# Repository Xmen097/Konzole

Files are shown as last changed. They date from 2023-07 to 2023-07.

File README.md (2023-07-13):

# Konzole
Herní konzole s Atmega328 vytvořená v rámci kroužku v DDM Praha 6.

##### Hardware
- TFT display 320x240
- Custom joystick
- 8 tlačítek
- IR vysílač a přijímač
- Otočný potenciometr
- Nabíjecí li-ion baterie s nabíjecím obvodem na micro USB

##### Software
Implementovány byly hry:
 Pong, Tetris, Snake (credits: Vojtěch Černý), pacman, Space shooter

##### Obrázky
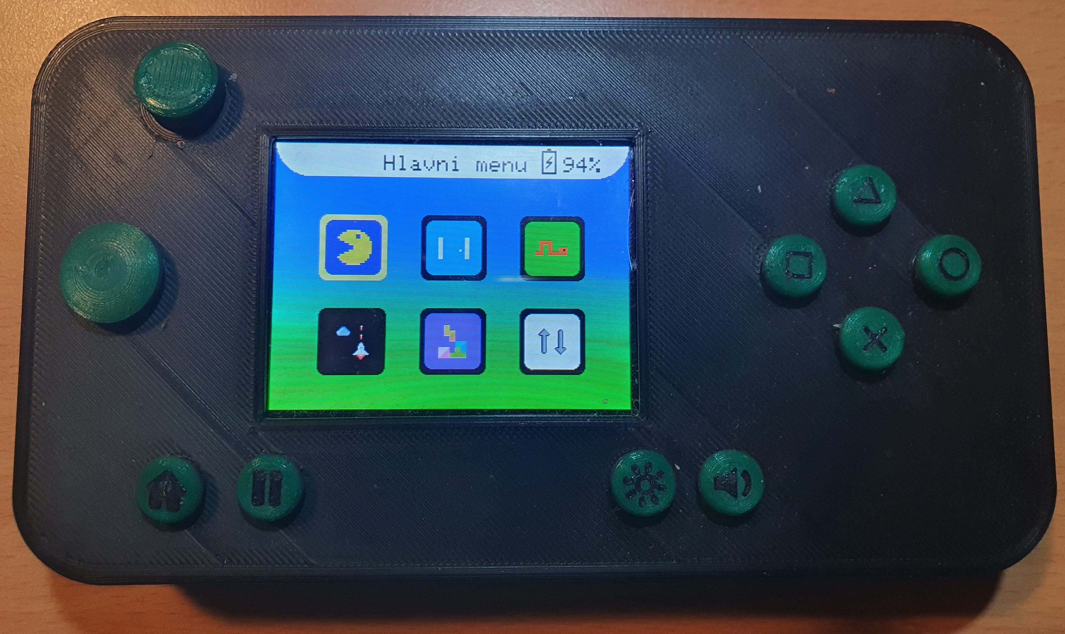
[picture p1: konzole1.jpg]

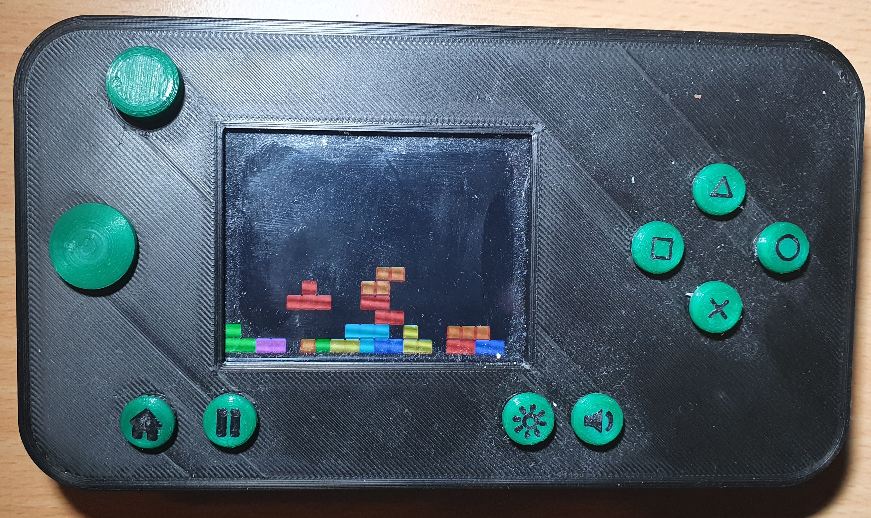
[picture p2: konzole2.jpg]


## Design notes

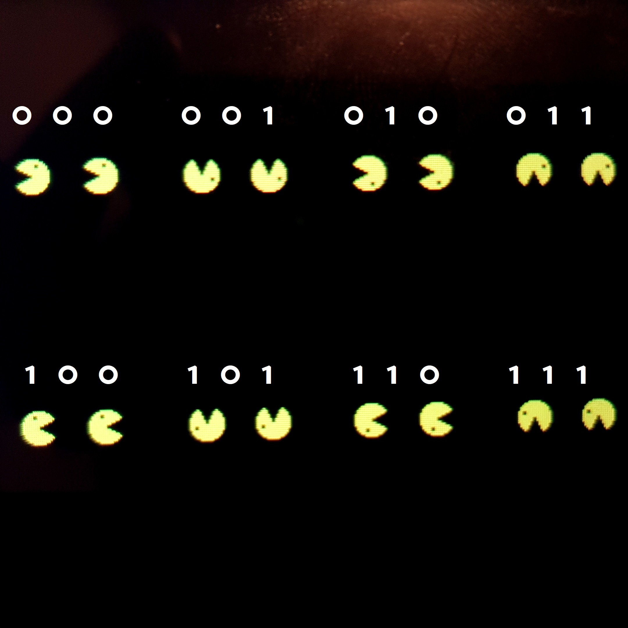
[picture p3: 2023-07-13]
konzole_smery.jpg

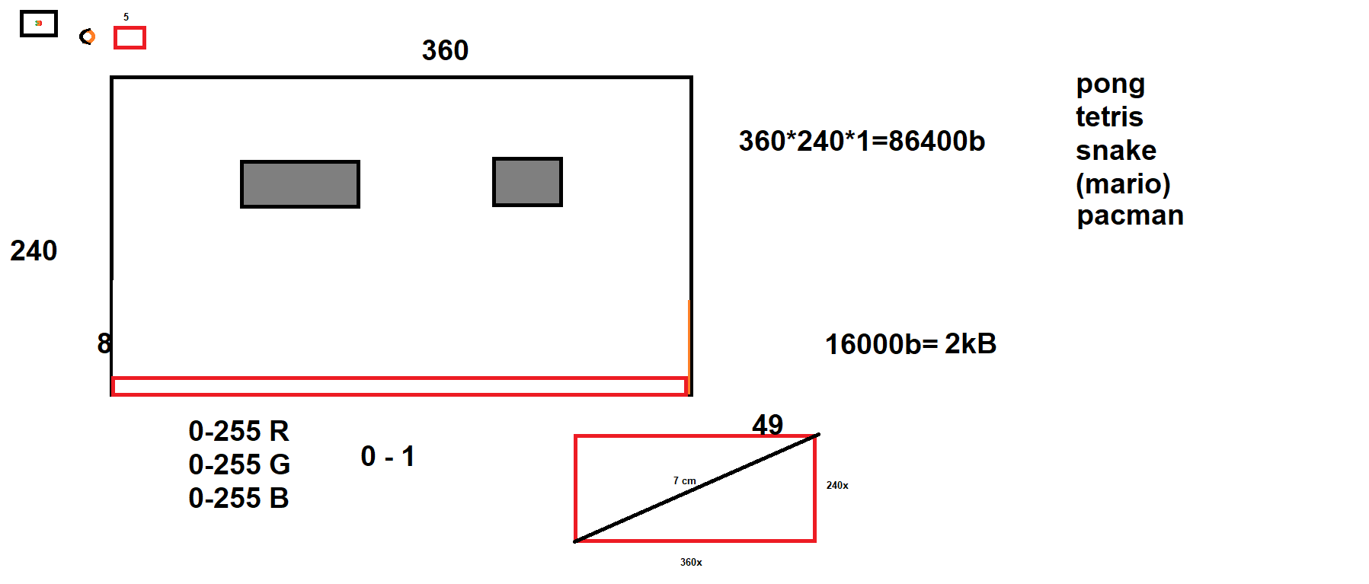
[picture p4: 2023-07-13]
konzole.png

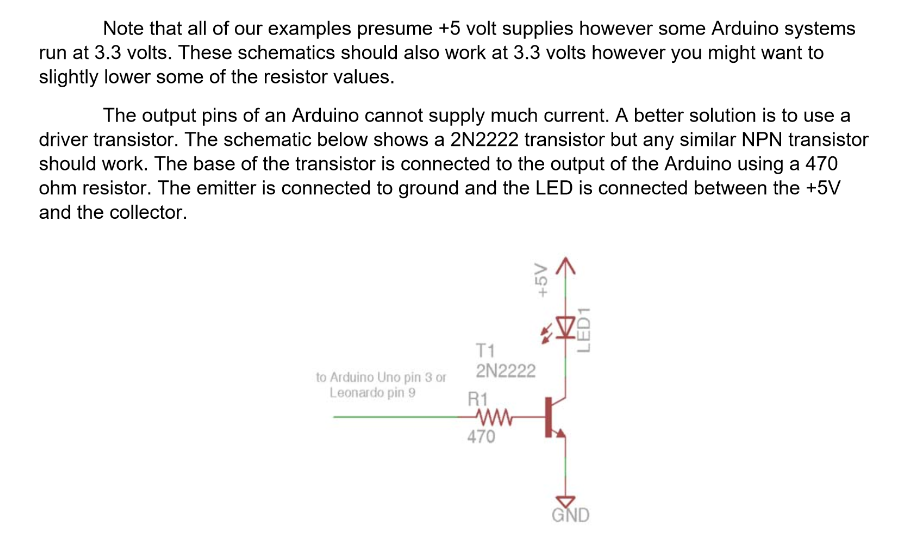
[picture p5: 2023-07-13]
IR drive circuit.png

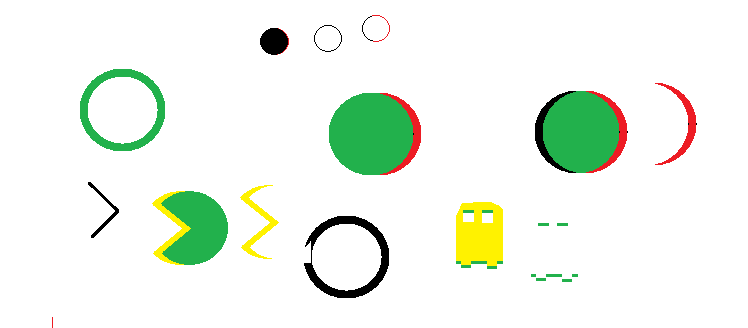
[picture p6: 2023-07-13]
rendering.png

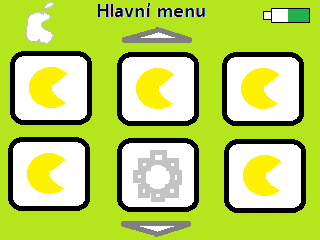
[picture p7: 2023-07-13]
hlavni menu.png

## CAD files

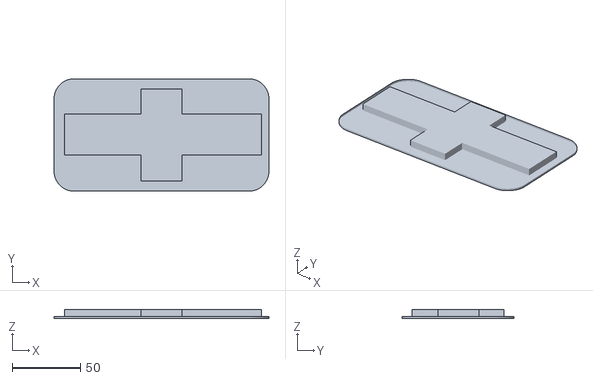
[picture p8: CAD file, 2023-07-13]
export/zada.stl
157.0 x 82.0 x 6.50

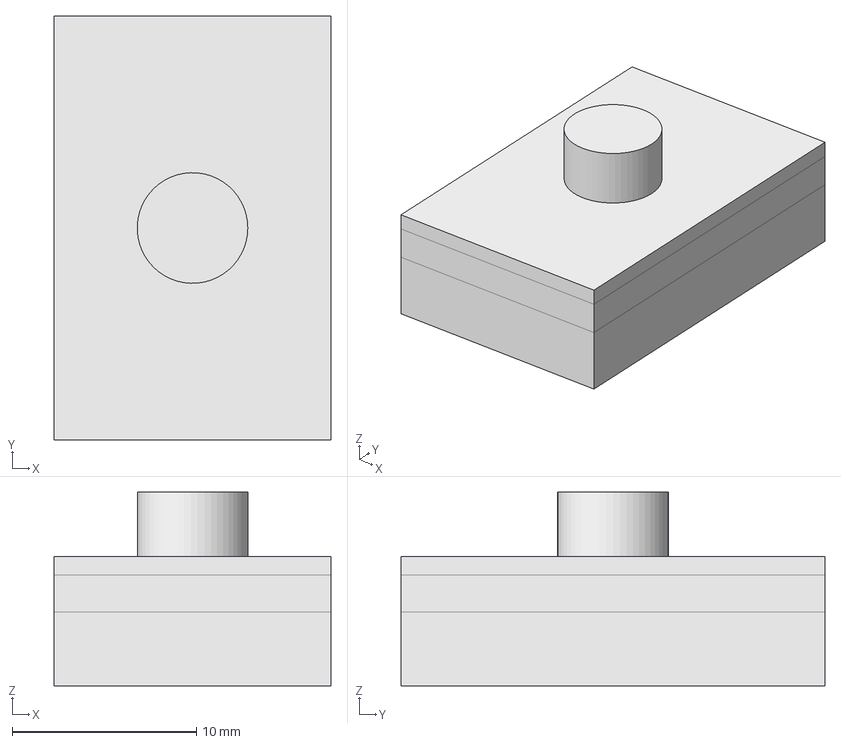
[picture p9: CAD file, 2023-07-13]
Konzole - modely/Joystick.FCStd
15.0 x 23.0 x 10.5 mm

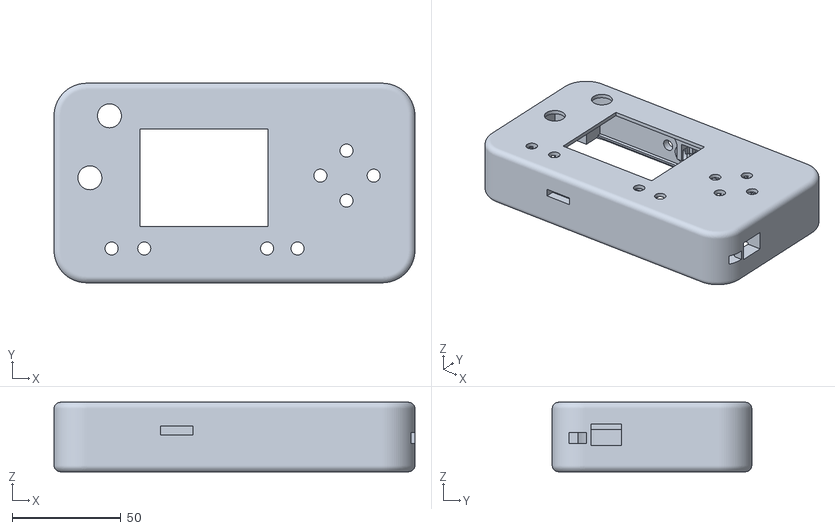
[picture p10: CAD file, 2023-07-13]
export/krabicka.stl
166.0 x 91.8 x 32.0

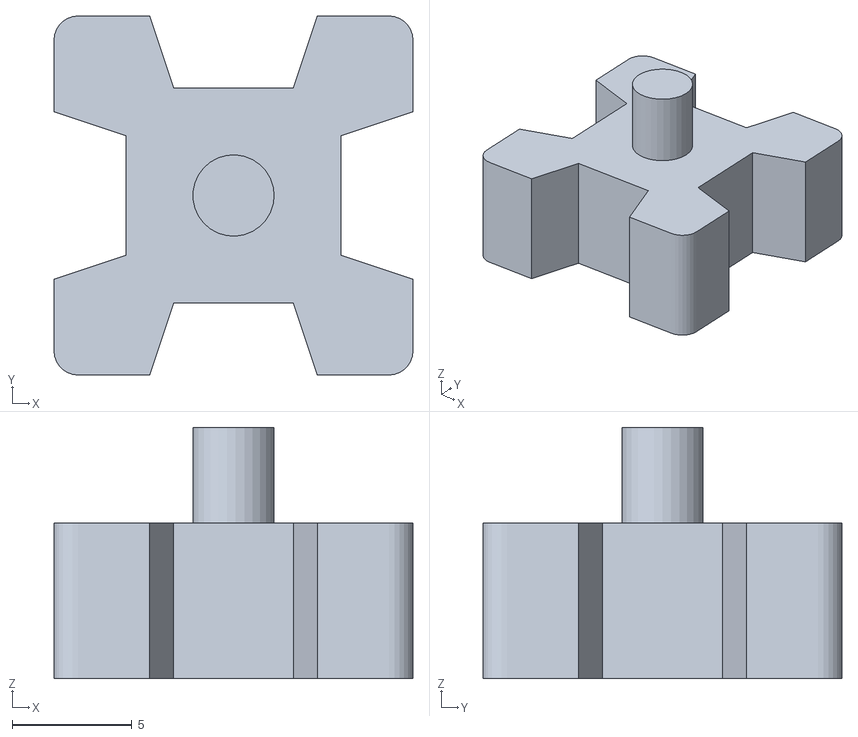
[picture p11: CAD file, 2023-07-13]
Konzole - modely/joystick_middle.stl
15.0 x 15.0 x 10.5

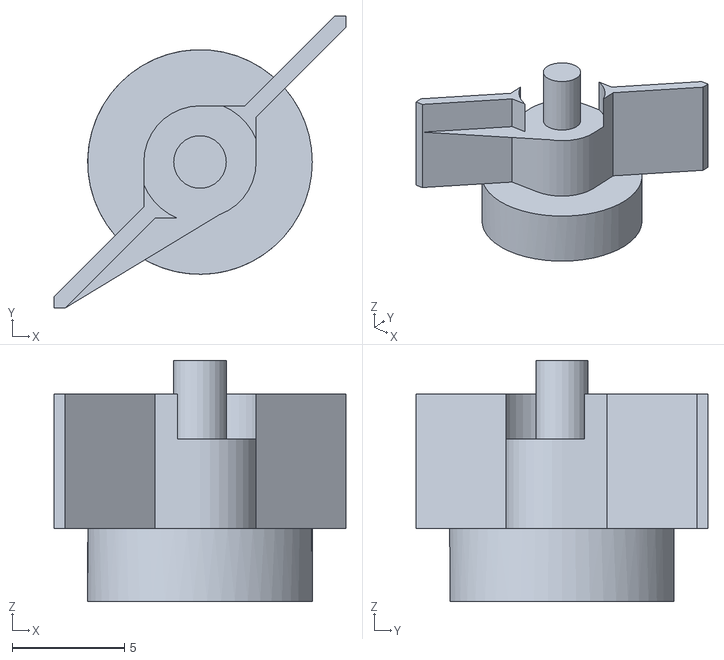
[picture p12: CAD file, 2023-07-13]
export/tlacitko_spodek.stl
13.0 x 13.0 x 10.8

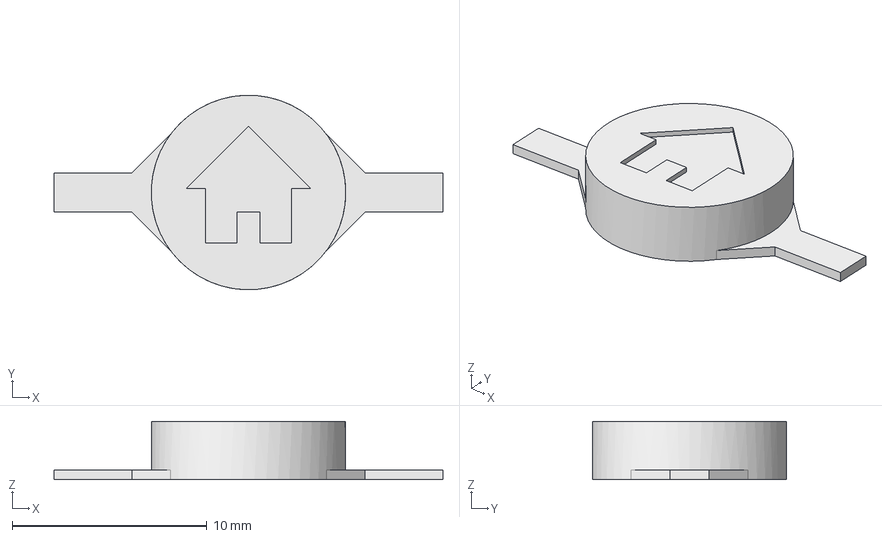
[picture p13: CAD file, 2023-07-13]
Konzole - modely/Test_tlacitek.FCStd
20.0 x 10.00 x 3.00 mm

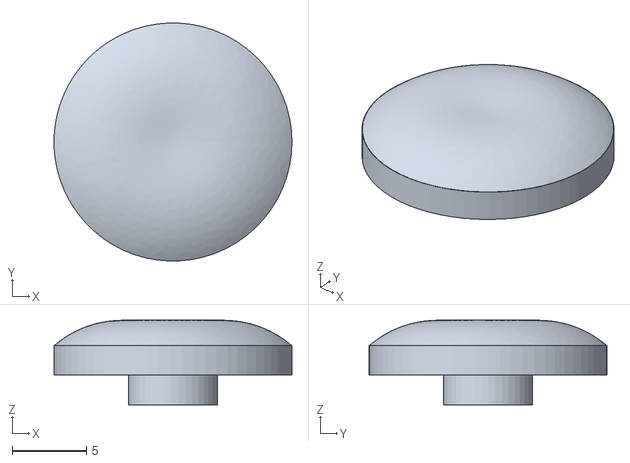
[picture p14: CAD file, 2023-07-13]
export/joystick_hmatnik.stl
16.0 x 16.0 x 5.69

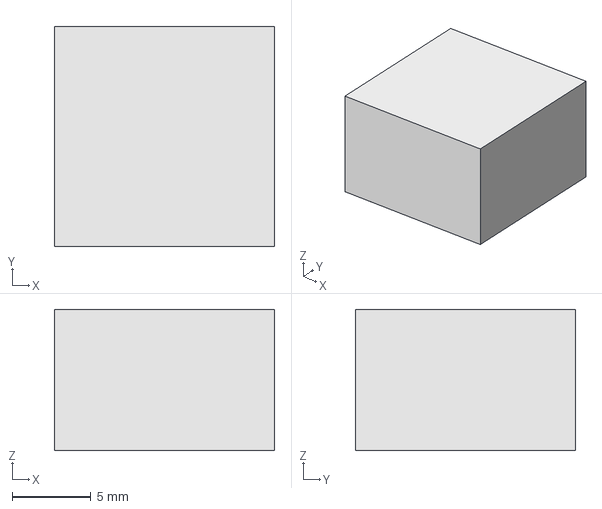
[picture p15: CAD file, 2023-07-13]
Konzole - modely/Master.FCStd
14.0 x 14.0 x 9.00 mm

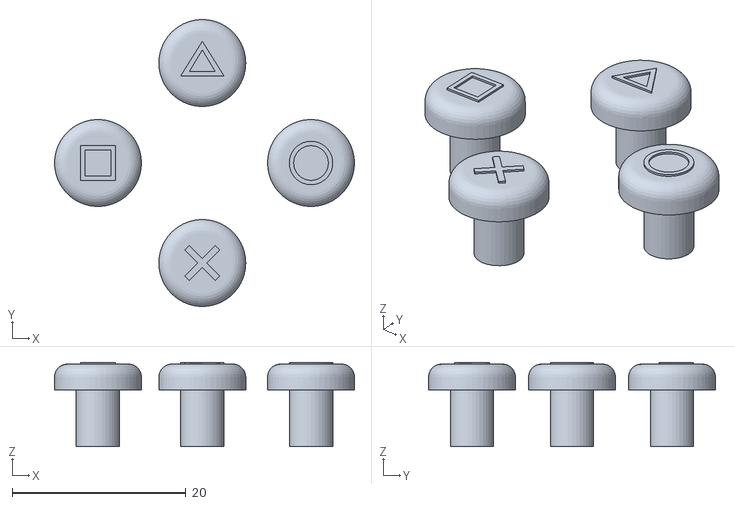
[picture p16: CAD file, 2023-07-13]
export/tlacitka_napravo.stl
34.5 x 33.0 x 9.70

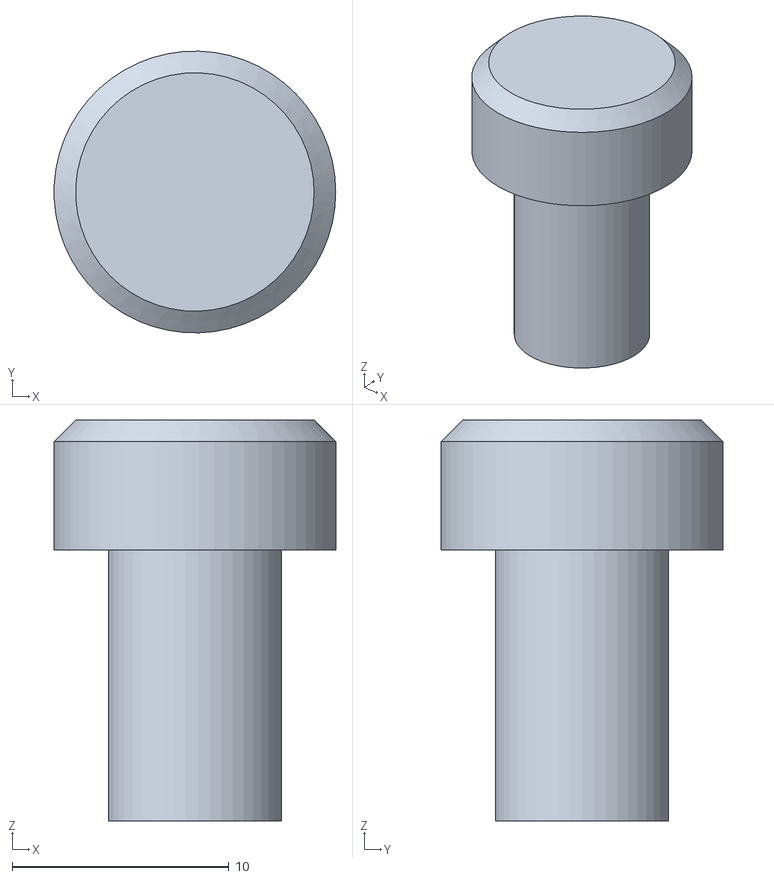
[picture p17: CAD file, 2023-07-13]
export/hlasitost.stl
13.0 x 13.0 x 18.5

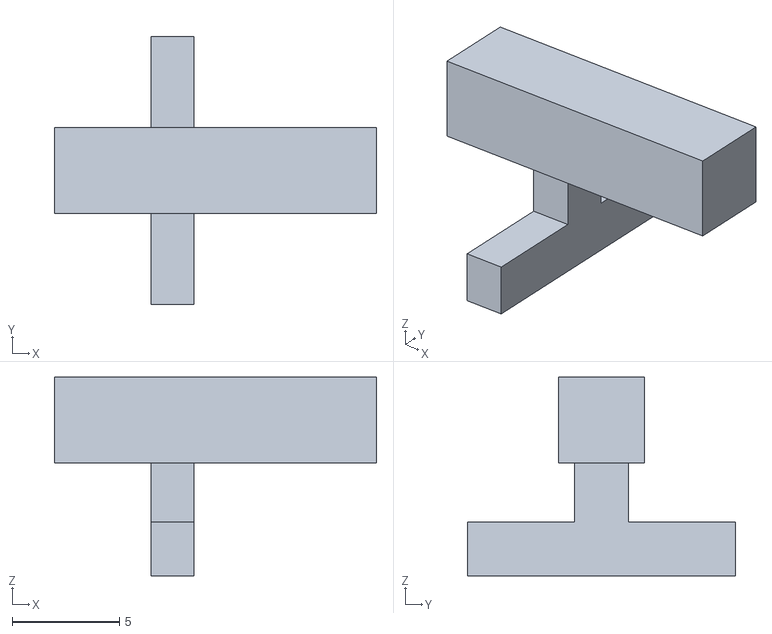
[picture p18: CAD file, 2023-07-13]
export/prepinac.stl
15.0 x 12.5 x 9.25

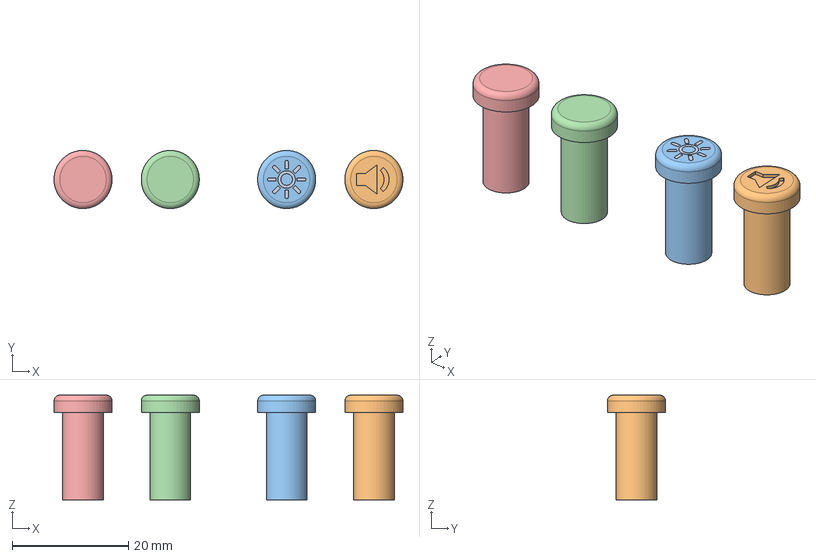
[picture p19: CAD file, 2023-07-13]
Konzole - modely/Button.FCStd
60.0 x 10.00 x 18.0 mm
ZákladTlačítka
TlacitkoMute
TlacitkoJas
TlacitkoPause
TlacitkoHome

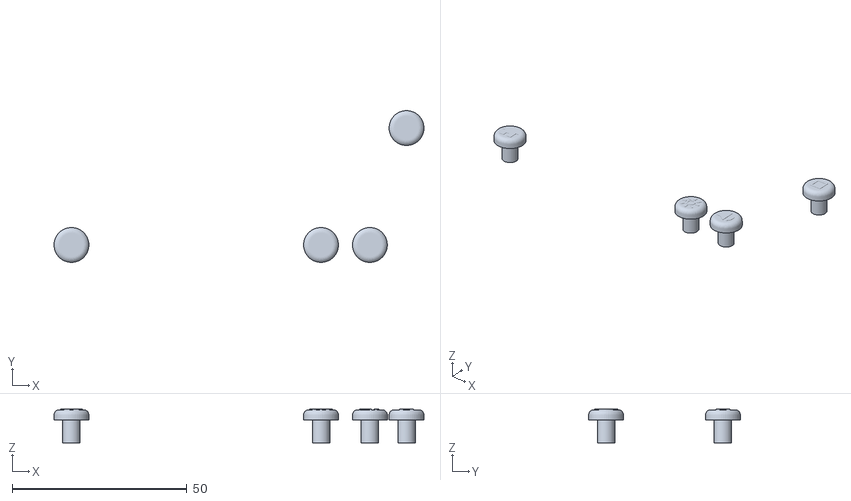
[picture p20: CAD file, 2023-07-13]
export/tlacitka_repair.stl
106.0 x 43.5 x 9.70

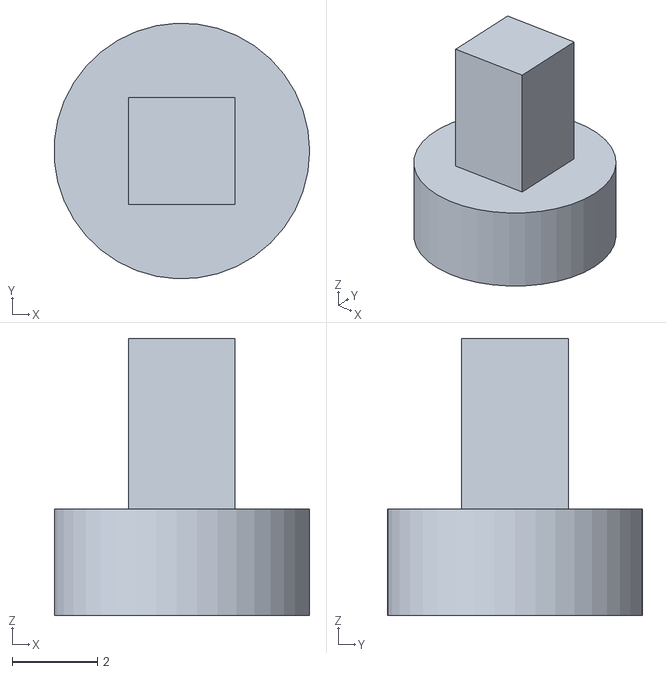
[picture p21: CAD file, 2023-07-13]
export/joystick_spodek.stl
5.99 x 6.00 x 6.50

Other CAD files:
Konzole - modely/test.stl
Konzole - modely/joystick_under.stl
Konzole - modely/joystick_top.stl
Konzole - modely/joystick_bottom.stl
export/joystick_prostredek.stl
export/tlacitka_akcni.stl

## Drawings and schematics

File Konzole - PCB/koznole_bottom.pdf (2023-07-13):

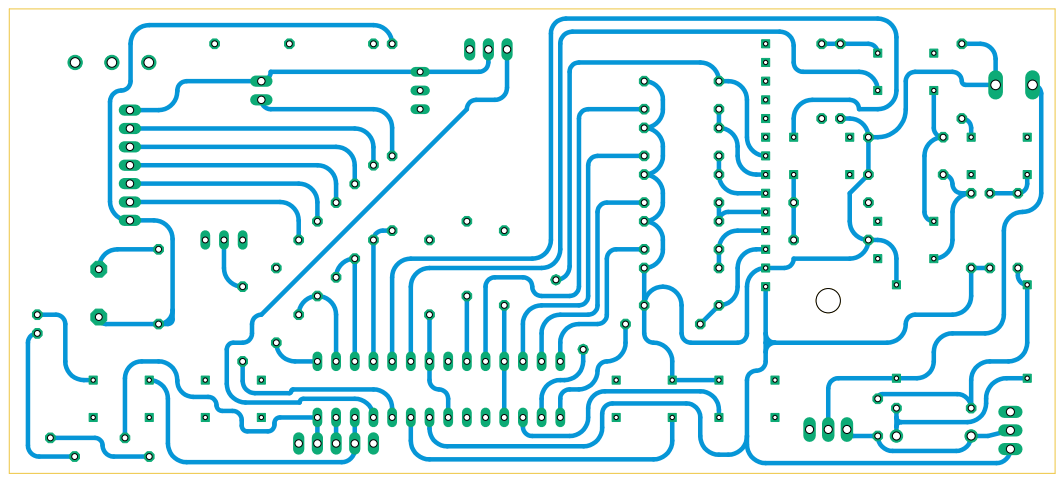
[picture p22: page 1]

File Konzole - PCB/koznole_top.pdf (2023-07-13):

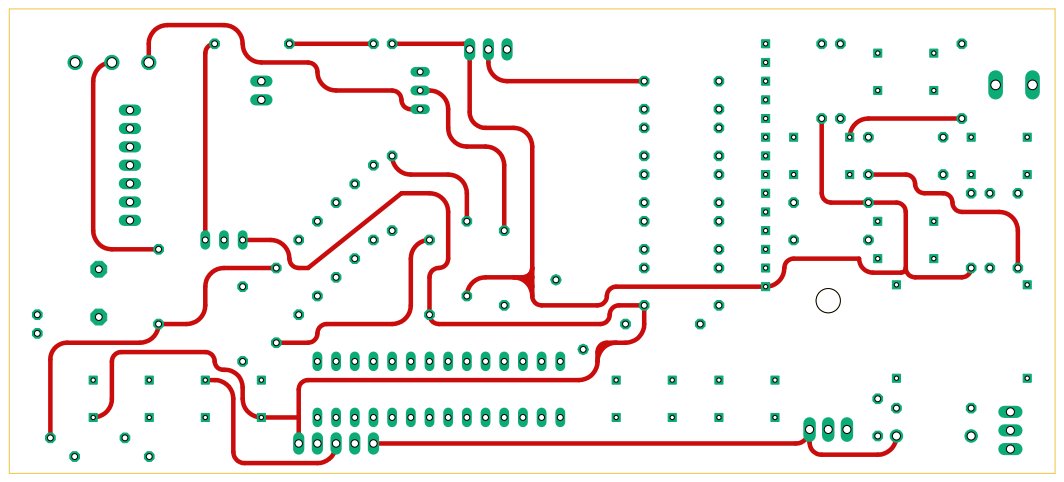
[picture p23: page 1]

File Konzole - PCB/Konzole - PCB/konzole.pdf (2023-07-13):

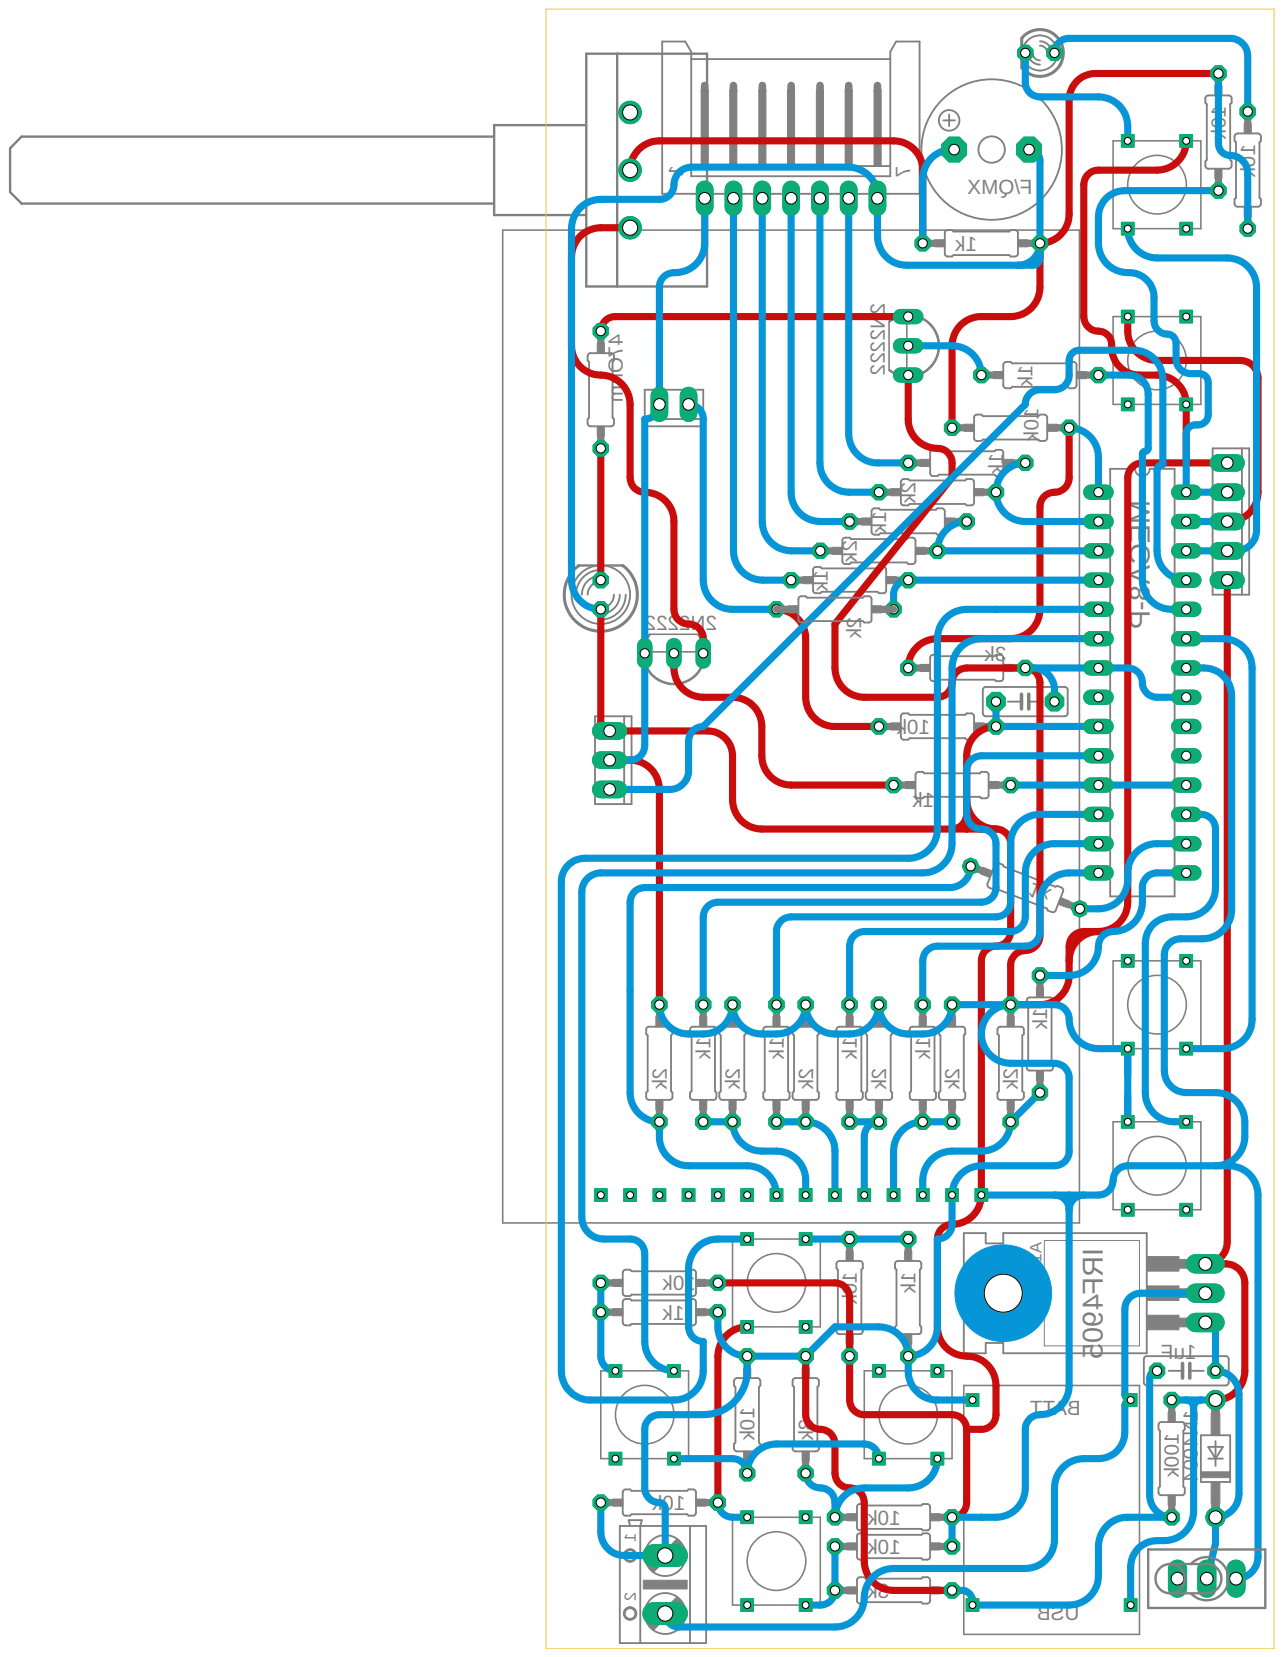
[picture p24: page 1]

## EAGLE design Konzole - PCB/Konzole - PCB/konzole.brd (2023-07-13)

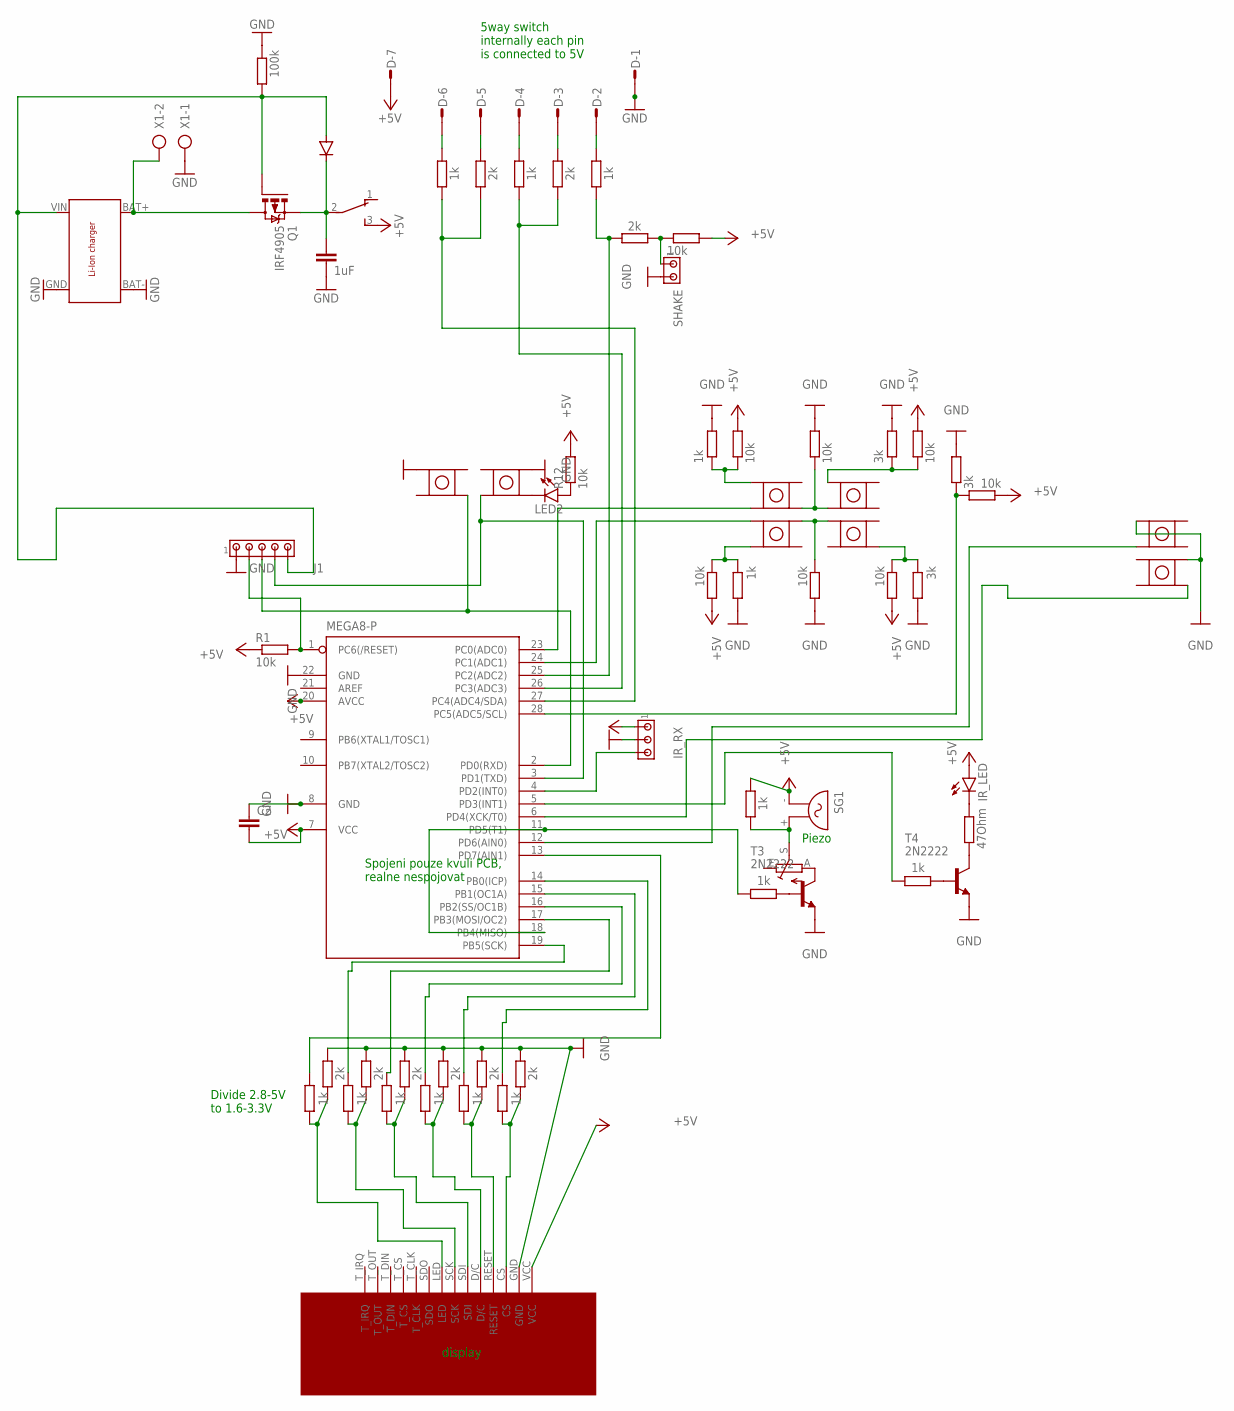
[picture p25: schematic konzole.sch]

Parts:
C1: 1uF; C050-025X075
C2: C5/2.5; C5B2.5
D: L07P
D1: 1N4004; DO41-10
IC1: MEGA8-P; DIL28-3
IR_LED: LED5MM
IR_RX: MTA03-100; 10X03MTA
J1: MTA05-100; 10X05MTA
LED2: LED3MM
Q1: IRF4905; TO220BH
R1, R12, R14, R16, R18, R20, R22, R23, R29, R49: 10k; 0207/10
R2, R4, R6, R8, R10, R15, R19, R24, R26, R27, R33, R35, R38, R40: 1k; 0207/10
R3, R5, R7, R9, R11, R25, R36, R39, R41: 2k; 0207/10
R13, R17, R21: 3k; 0207/10
R28: TRIM_EU-CIP20C-6MM; CIP20C-6MM
R34: 47Ohm; 0207/10
R42: 100k; 0207/10
S1: TL36PO; TL3XPO
SG1: F/QMX
SHAKE: MTA02-100; 10X02MTA
T3, T4: 2N2222; TO92-EBC-OVAL
U$1, U$3, U$4, U$5, U$6, U$7, U$8, U$9: TACT
U$2: DISPLAY
U$10: LI_ION_CHARGER
X1: AK500/2

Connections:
+5V: C2.2, D.7, IC1.7 (VCC), IC1.20 (AVCC), IR_LED.A, IR_RX.1, R1.1, R12.2, R14.2, R16.2, R18.2, R20.2, R27.2, R29.1, R49.2, S1.3 (S), SG1.- (1), U$2.VCC
GND: C1.2, C2.1, D.1, IC1.8 (GND), IC1.22 (GND), IR_RX.2, J1.1, R3.2, R5.2, R7.2, R9.2, R11.2, R13.2, R15.2, R17.2, R19.2, R21.2, R22.2, R23.2, R25.2, R42.2, SHAKE.2, T3.E, T4.E, U$2.GND, U$6.P$4 (4), U$7.P$1 (1), U$8.P$1 (1), U$9.P$4 (4), U$10.BAT-, U$10.GND, X1.1
unnamed: IC1.1 (PC6(/RESET)), J1.2, R1.2
unnamed: R2.2, R3.1, U$2.CS
unnamed: R4.2, R5.1, U$2.RESET
unnamed: R6.2, R7.1, U$2.D/C
unnamed: R8.2, R9.1, U$2.SDI
unnamed: R10.2, R11.1, U$2.SCK
unnamed: IC1.17 (PB3(MOSI/OC2)), R8.1
unnamed: IC1.13 (PD7(AIN1)), R24.1
unnamed: IC1.16 (PB2(SS/OC1B)), R6.1
unnamed: IC1.15 (PB1(OC1A)), R4.1
unnamed: R14.1, R15.1, U$1.P$1 (1)
unnamed: R27.1, R28.S, SG1.+ (2)
unnamed: IC1.19 (PB5(SCK)), R10.1
unnamed: R16.1, R17.1, U$5.P$1 (1)
unnamed: R18.1, R19.1, U$3.P$2 (2)
unnamed: R20.1, R21.1, U$4.P$3 (3)
unnamed: R33.2, T4.B
unnamed: LED2.K (C), U$9.P$3 (3)
unnamed: IC1.2 (PD0(RXD)), J1.3, U$8.P$3 (3)
unnamed: IC1.3 (PD1(TXD)), J1.4, U$9.P$2 (2)
unnamed: R23.1, U$3.P$4 (4), U$4.P$1 (1)
unnamed: R22.1, U$1.P$3 (3), U$5.P$2 (2)
unnamed: IC1.23 (PC0(ADC0)), U$1.P$2 (2)
unnamed: R24.2, R25.1, U$2.LED
unnamed: IC1.24 (PC1(ADC1)), U$3.P$1 (1)
unnamed: R34.1, T4.C
unnamed: IC1.11 (PD5(T1)), IC1.18 (PB4(MISO)), R26.1
unnamed: R26.2, T3.B
unnamed: R28.A, T3.C
unnamed: IC1.14 (PB0(ICP)), R2.1
unnamed: IC1.12 (PD6(AIN0)), U$7.P$2 (2)
unnamed: IC1.28 (PC5(ADC5/SCL)), R13.1, R29.2
unnamed: IC1.6 (PD4(XCK/T0)), U$6.P$3 (3)
unnamed: LED2.A, R12.1
unnamed: IC1.4 (PD2(INT0)), IR_RX.3
unnamed: IR_LED.K (C), R34.2
unnamed: IC1.5 (PD3(INT1)), R33.1
unnamed: D.6, R38.2
unnamed: D.5, R36.2
unnamed: D.4, R35.2
unnamed: Q1.D, U$10.BAT+, X1.2
unnamed: D.3, R39.2
unnamed: D.2, R40.2
unnamed: IC1.26 (PC3(ADC3)), R35.1, R39.1
unnamed: R41.1, R49.1, SHAKE.1
unnamed: D1.A, J1.5, Q1.G, R42.1, U$10.VIN
unnamed: C1.1, D1.C, Q1.S, S1.2
unnamed: IC1.25 (PC2(ADC2)), R40.1, R41.2
unnamed: IC1.27 (PC4(ADC4/SDA)), R36.1, R38.1

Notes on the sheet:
Spojeni pouze kvuli PCB, realne nespojovat
display
Divide 2.8-5V to 1.6-3.3V
Piezo
5way switch internally each pin is connected to 5V

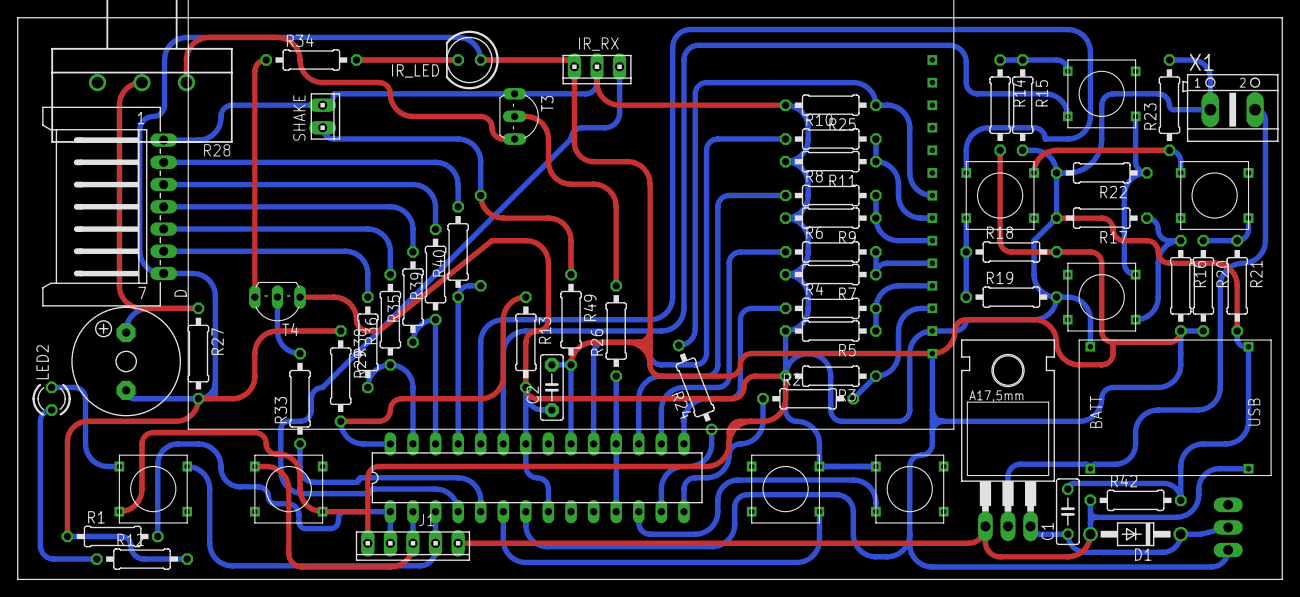
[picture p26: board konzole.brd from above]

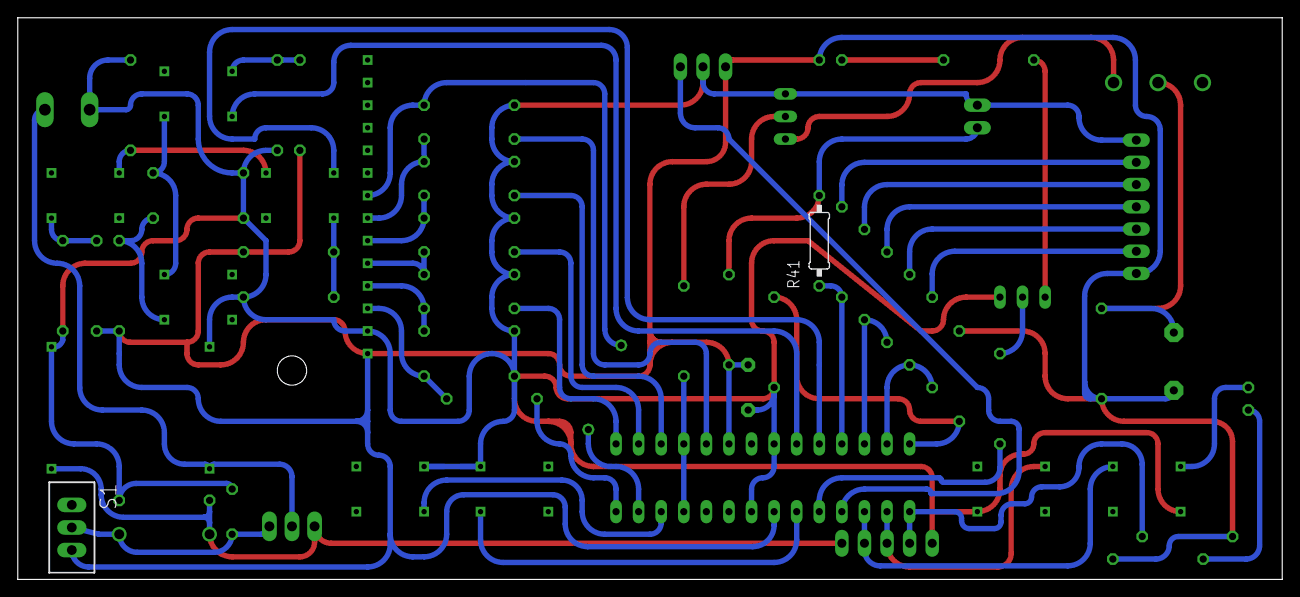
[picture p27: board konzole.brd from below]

Board: 2 copper layers, 142.2 x 63.2 mm, 65 parts (2 on the bottom side), 51 nets.

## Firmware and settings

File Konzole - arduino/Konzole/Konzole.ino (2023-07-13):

#include "define.h"
#include <EEPROM.h>

enum games:uint8_t {
  Menu, Pacman, Pong, Snake, Shooter, Tetris, Settings
};
void (*game_setups[])() = {menu::setup, pacman::setup, pong::setup, snake::setup, shooter::setup, tetris::setup, test::setup};
void (*game_loops[])() = {menu::loop, pacman::loop, pong::loop, snake::loop, shooter::loop, tetris::loop, test::loop};
void (*game_destructors[])() = {menu::destruct, pacman::destruct, pong::destruct, snake::destruct, shooter::destruct, tetris::destruct, test::destruct};


games current_game = Menu;
long bat_pointer = 0;
uint32_t timer = 0;

void setup() {
  tft.setup(255);
  Input::setup();
  Input::loop(); // to avoid false read during first loop
  game_setups[current_game]();
}
void loop() {
  Input::loop();
  sys_functions();
  game_loops[current_game]();
  frame_time_stabilizer();
}

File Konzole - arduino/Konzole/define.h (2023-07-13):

#include <Arduino.h>
#include "pin_define.h"

//colors
#define color_black 0x0000
#define color_white 0xffff
#define color_blue 0x03bd
#define color_yellow 0xFF0C
#define color_light_blue 0x1e1e
#define color_lime 0x3702
#define color_green 0x3702
#define color_red 0xf881
#define color_gray 0x8430
#define color_purple 0x781F
#define color_dark_purple 0x2011


#define screen_height 240
#define screen_width 320
  
typedef uint16_t color_t;
class PDQ_ILI9341;
extern const PROGMEM uint8_t None[][5];

extern bool sys_functions_disabled;
extern bool game_paused;

bool button_debounced(int i);
int get_battery();
static inline int8_t sign(int val);
void draw_image(int pos_x, int pos_y, uint8_t (*data)[5], byte len, color_t *colors, byte size_y, color_t background);
extern const int bottom_button_count;
extern const int bottom_button_pins[];


enum games: uint8_t;
extern games current_game;
extern void (*game_setups[])();
extern void (*game_loops[])();

enum input_type {
  dpad_up,
  shake_sensor,
  dpad_down,
  dpad_right,
  dpad_left,
  dpad_click,
  button_up,
  button_down,
  button_left,
  button_right,
  button_menu,
  button_pause,
  button_brightness,
  button_volume,
};

enum Direction {
  direction_none,
  direction_up,
  direction_down,
  direction_left,
  direction_right,
};

class Display {
  public:
  Display(PDQ_ILI9341 *tft);
  setup(uint8_t brightness);
  fillScreen(color_t color);
  fillRect(int x, int y, int w, int h, color_t color);
  println(char *s);
  print(char *s);
  println(__FlashStringHelper *s);
  print(__FlashStringHelper *s);
  setTextColor(color_t color);
  setTextSize(int size);
  setCursor(int x, int y);
  drawCircle(int x0, int y0, int r, color_t color);
  fillCircle(int x0, int y0, int r, color_t color);
  drawPixel(int x, int y, color_t color);
  drawHLine(int x, int y, int d, color_t color);
  drawVLine(int x, int y, int d, color_t color);
  fillTriangle(int x0, int y0, int x1, int y1, int x2, int y2, color_t color);
  drawTriangle(int x0, int y0, int x1, int y1, int x2, int y2, color_t color);
  fillRoundRect(int x, int y, int w, int h, int r, color_t color);
  drawLine(int x0, int y0, int x1, int y1, color_t color);
  setBrightness(uint8_t brightness);

  const int width = 320;
  const int height = 240;
  private:
   PDQ_ILI9341 *tft;
};
extern Display tft;

class Entity;

class Collidable {
  public:
   virtual Direction collide(Entity *entity, Direction direction);
};

class Entity: public Collidable {
  public:  
    uint8_t (*LR_data)[5];
    uint8_t (*UD_data)[5];
    uint8_t LR_length;
    uint8_t UD_length;
    color_t *colors;
    uint8_t size_x;
    uint8_t size_y;
    int pos_x;
    int pos_y;
    int speed_x;
    int speed_y;
    Entity(uint8_t (*LR_data)[5], uint8_t (*UD_data)[5], color_t *colors, uint8_t LR_length, uint8_t UD_length);
    setSize(uint8_t size_x, uint8_t size_y);
    setPosition(int pos_x, int pos_y);
    setSpeed(int speed_x, int speed_y);
    move(Direction dir);
    move_stable(Direction dir);
    move();
    move(uint8_t count);
    Direction move_and_collide(Collidable *collidable);
    Direction will_collide(Collidable *collidable);
    Direction will_collide(Collidable *collidable, Direction direction);
    Direction collide(Entity *entity, Direction direction);
    draw(bool mirror_v, bool mirror_h, bool rotate);
    draw();
    hide();
    move_x(bool direction);
    move_y(bool direction);
    move_x(bool direction, bool mirror_v, bool mirror_h, bool rotate);
    move_y(bool direction, bool mirror_v, bool mirror_h, bool rotate);
    Direction next_move();
  private:
    bool current_mirror_v;
    bool current_mirror_h;
    bool current_rotate;
    unsigned long moved_x;
    unsigned long moved_y;
    _move_x(bool direction, bool mirror_v, bool mirror_h, bool rotate);
    _move_y(bool direction, bool mirror_v, bool mirror_h, bool rotate);
    _draw(bool mirror_v, bool mirror_h, bool rotate);
};

class Tile_8 {
  public:
  color_t color;
  uint8_t *data;
  bool h_invert;
  bool v_invert;
  uint8_t size_x;
  uint8_t size_y;
  uint8_t get_row(uint8_t row);
  Tile_8(uint8_t *data, color_t color, bool h_invert=false, bool v_invert=false);
  draw(int x, int y);
  draw_2x(int x, int y);
  bool pixel_data(uint8_t x, uint8_t y);
};

class Background: public Collidable {
  public:
    draw();
    Direction collide(Entity *entity, Direction direction);
    color_t pixel_color(int x, int y);
};

class BG_solid : public Background {
  public:
    color_t color;
    BG_solid(color_t color);
    BG_solid(color_t color, int x, int y, int w, int h);
    draw();
    Direction collide(Entity *entity, Direction direction);
  private:
    int x1 = 0;
    int y1 = 0;
    int x2 = 320;
    int y2 = 240;
};
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

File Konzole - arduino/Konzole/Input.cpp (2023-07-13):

#include "define.h"

#define diff(a,b) (a>=b ? a-b : b-a)


#define dpad_value_left 330
#define dpad_value_middle 0
#define dpad_value_right 590

#define buttons_value_left 356
#define buttons_value_middle 527
#define buttons_value_right 840


namespace Input {
  const byte input_axis[5] = {axis_left1, axis_left2, axis_left3, axis_right1, axis_right2}; 
  int axis_values[5] = {0};
  int prev_axis_values[5] = {0};
  bool button_down[14] = {false};
  bool prev_button_down[14] = {false};
  const byte bottom_buttons[] = {button_bottom1_pin, button_bottom2_pin, button_bottom3_pin, button_bottom4_pin};

  
  const long voltage_multiplier = 1023;
  const long axis_treshold = 40*voltage_multiplier;
  const int change_treshold = 20;
  
  void setup() {
    pinMode(button_bottom1_pin, INPUT_PULLUP);
    pinMode(button_bottom2_pin, INPUT_PULLUP);
    pinMode(button_bottom3_pin, INPUT_PULLUP);
    pinMode(button_bottom4_pin, INPUT_PULLUP);
    analogReference(INTERNAL);
  }
  
  int axis;
  int but;
  long voltage_value;
  
  void loop() {
    for (int i=0; i<14; i++) {
      prev_button_down[i] = button_down[i];
    }
    voltage_value = analogRead(axis_battery);
     for (axis=0; axis<3; axis++) {
      prev_axis_values[axis] = axis_values[axis];
      axis_values[axis] = analogRead(input_axis[axis]);
      if (diff(prev_axis_values[axis], axis_values[axis]) < change_treshold) {
        long adjusted_value = axis_values[axis] * voltage_multiplier;
        if (diff(adjusted_value, voltage_value*dpad_value_left) < axis_treshold) {
          button_down[axis*2] = true;
          button_down[axis*2+1] = false;
        } else if (diff(adjusted_value, voltage_value*dpad_value_right) < axis_treshold) {
          button_down[axis*2] = false;
          button_down[axis*2+1] = true;
        } else if (diff(adjusted_value, voltage_value*dpad_value_middle) < axis_treshold) {
          button_down[axis*2] = true;
          button_down[axis*2+1] = true;
        } else {
          button_down[axis*2] = false;
          button_down[axis*2+1] = false;
        }
      }
     }
     for (axis=3; axis<5; axis++) {
      prev_axis_values[axis] = axis_values[axis];
      axis_values[axis] = analogRead(input_axis[axis]);
      if (diff(prev_axis_values[axis], axis_values[axis]) < change_treshold) {
        long adjusted_value = axis_values[axis] * voltage_multiplier;
        if (diff(adjusted_value, voltage_value*buttons_value_left) < axis_treshold) {
          button_down[axis*2] = true;
          button_down[axis*2+1] = false;
        } else if (diff(adjusted_value, voltage_value*buttons_value_right) < axis_treshold) {
          button_down[axis*2] = false;
          button_down[axis*2+1] = true;
        } else if (diff(adjusted_value, voltage_value*buttons_value_middle) < axis_treshold) {
          button_down[axis*2] = true;
          button_down[axis*2+1] = true;
        } else {
          button_down[axis*2] = false;
          button_down[axis*2+1] = false;
        }
      }
     }
     for (but=0; but<4; but++) {
      button_down[10+but] = digitalRead(bottom_buttons[but]);
     }
  }
  
  bool is_pressed(input_type button) {
    return button_down[(byte)button];
  }
  bool is_just_pressed(input_type button) {
    return button_down[(byte)button] && !prev_button_down[(byte)button];
  }
  bool is_just_released(input_type button) {
    return !button_down[(byte)button] && prev_button_down[(byte)button];
  }
  Direction dpad_direction() {
    if (Input::is_pressed(dpad_right)) {
      return direction_right;
    }
      
    if (Input::is_pressed(dpad_down)) {
      return direction_down;
    }
      
    if (Input::is_pressed(dpad_left)) {
      return direction_left;
    }
      
    if (Input::is_pressed(dpad_up)) {
      return direction_up;
    }
    return direction_none;
  }
}

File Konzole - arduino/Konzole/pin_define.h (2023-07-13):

#define ILI9341_CS_PIN 8
#define ILI9341_DC_PIN 10
#define ILI9341_RST_PIN 7
#define ILI9341_LED_PIN 9
#define ILI9341_SAVE_SPI_SETTINGS 0

#define piezo_pin 5
#define ir_rx_pin 2
#define ir_tx_pin 3
#define led_pin 1
#define button_bottom1_pin 1
#define button_bottom2_pin 0
#define button_bottom3_pin 4
#define button_bottom4_pin 6

//input axis
#define axis_left1 A2
#define axis_left2 A3
#define axis_left3 A4
#define axis_right1 A0
#define axis_right2 A1
#define axis_battery A5

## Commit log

2023-07-13 Added to github
    [Button.FCStd, Joystick.FCStd, Krabicka_Simon.FCStd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]
2023-07-13 clean up
    [Krabicka_Simon.FCStd, Krabicka_Vojta.FCStd, krabicka_patrik.stl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]
